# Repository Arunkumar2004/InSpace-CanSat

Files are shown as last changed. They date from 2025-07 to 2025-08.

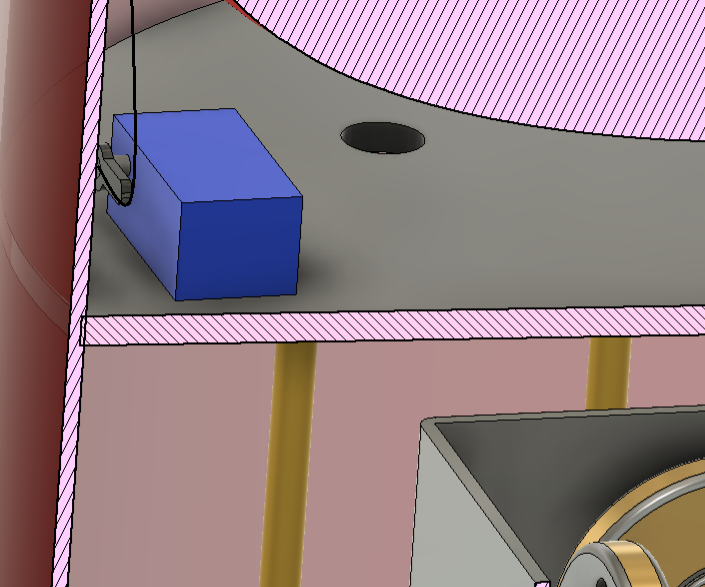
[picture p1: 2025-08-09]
IMAGE/General/para locked 1.png

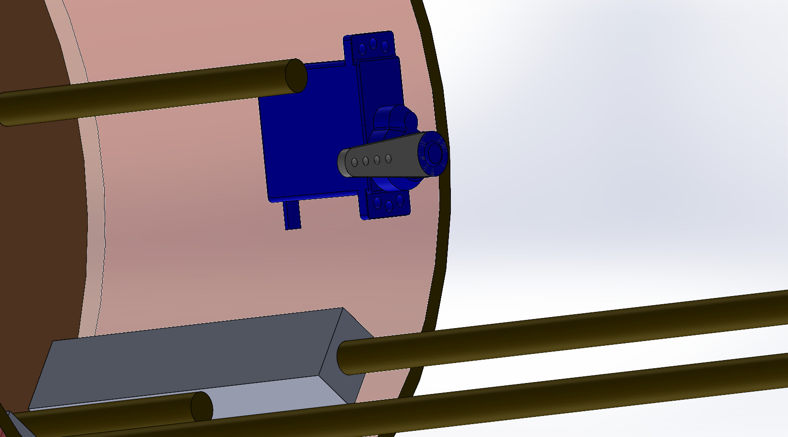
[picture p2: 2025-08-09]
IMAGE/General/Assem3.JPG

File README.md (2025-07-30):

# 🚀 INSPACE CanSat 2024-2025 – Final Stage Project

This repository contains all the work for our **CanSat project** developed for the **INSPACE CanSat Competition 2024-2025**.  
We are proud to announce that our team has been **selected for the Final Stage (Live Testing)**.

## 📌 Project Overview
Our CanSat is designed to perform a complete mission profile including:
- ✅ **CAD Design** – Full 3D modeling and structural analysis.
- ✅ **Avionics** – Flight computer, sensors, telemetry & power systems.
- ✅ **Payload** – Custom-designed scientific payload for data collection.
- ✅ **Deployment** – Safe separation and descent system.
- ✅ **Landing System** – Controlled recovery with parachute & stability testing.

## 📂 Repository Structure

## 🛰️ Technologies & Tools
- **Programming:** Python, Arduino (C/C++)
- **CAD & Simulation:** Fusion 360, SolidWorks
- **Electronics:** Teensy, Arduino Nano, Sensors (BMP, GPS, IMU)
- **Communication:** XBee Telemetry, Custom GCS Software

## 📡 Mission Objective
The goal of this CanSat is to:
- Capture real-time telemetry during flight.
- Deploy a payload safely using a controlled descent system.
- Record environmental data including temperature, pressure, and GPS coordinates.
- Successfully demonstrate deployment & landing during **INSPACE CanSat Live Testing**.

## 👨‍🚀 Team
- **Team Name:** PHOENIX
- **Members:** ARUNKUMAR D

## 🏆 Competition Status
✅ **Selected for Final Stage – Live Testing (2024-2025)**

## 📜 License
This project is licensed under the MIT License – see the [LICENSE](LICENSE) file for details.

---

### 🔗 Useful Links
- [INSPACE CanSat Competition Website](#)
- [Project Presentation](#)
- [Flight Test Videos](#)

---

⭐ **If you like this project, give it a star and follow our journey!**

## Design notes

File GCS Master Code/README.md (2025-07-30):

# CanSat GCS

Ground Control Station for Team Phoenix CanSat 2024.

## Structure
- `main.py`: Entry point
- `config/settings.py`: Serial config, team name, constants
- `serial_comm/`: Serial communication handling
- `gui/`: PyQt GUI components
- `data/`: Data logging and dummy data
- `assets/`: Images and static assets

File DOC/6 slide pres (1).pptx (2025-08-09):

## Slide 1

CanSat 2024
Preliminary Design Review (PDR)

TEAM PHOENIX

2024-ASI-CANSAT-012

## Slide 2

CANSAT configuration

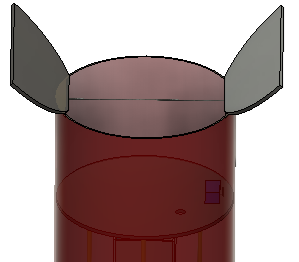
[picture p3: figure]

2nd Parachute deployed

Top Lib Opened

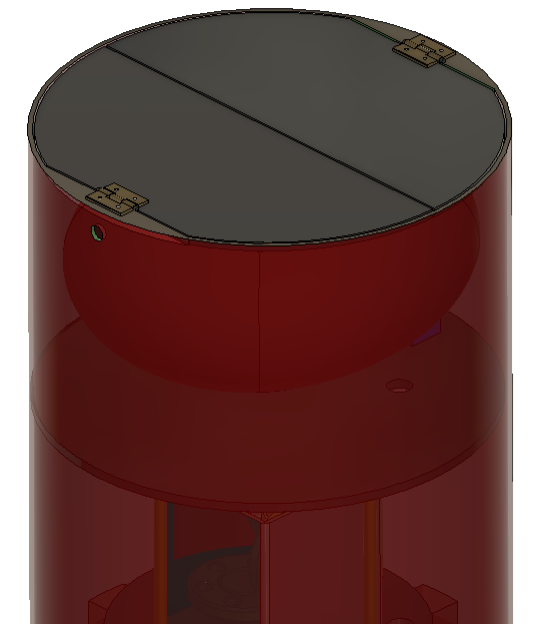
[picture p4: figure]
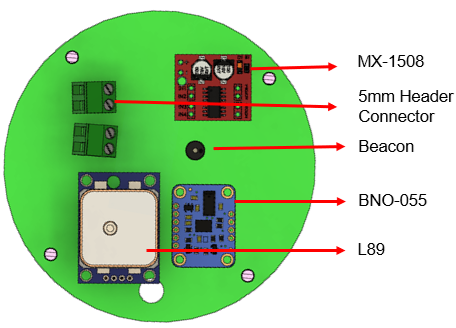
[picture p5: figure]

1st Circular PCB

Parachute Section

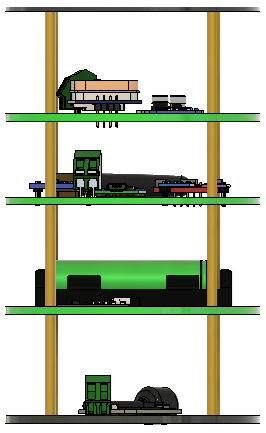
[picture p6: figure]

Payload

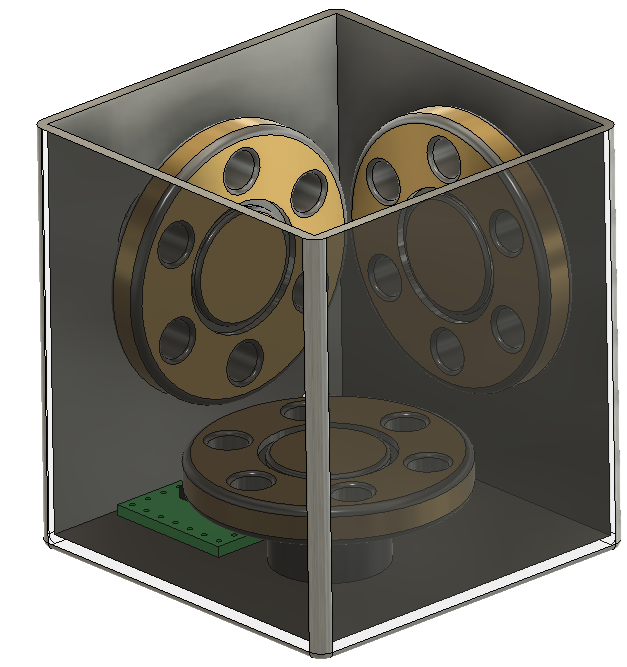
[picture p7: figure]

Gyro

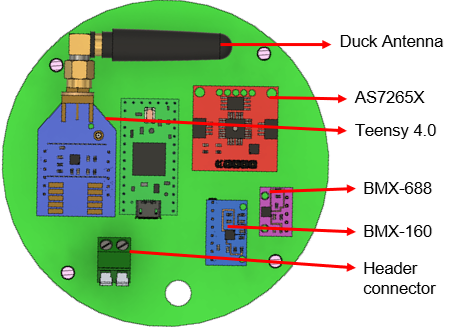
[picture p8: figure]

392MM

(Or)

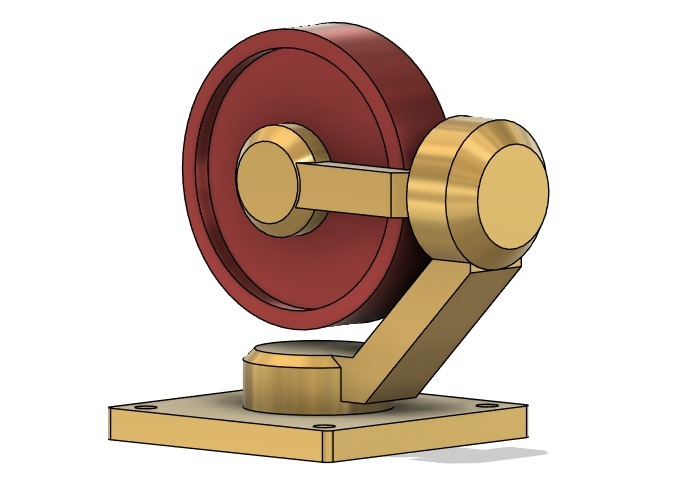
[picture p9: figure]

2nd circular PCB

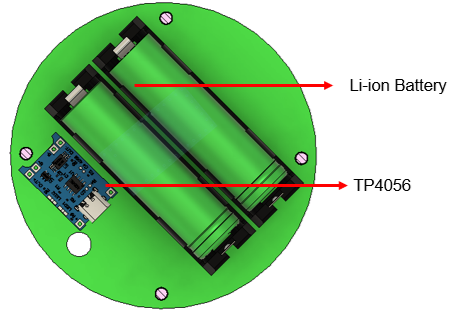
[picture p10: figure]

3rd Circular PCB

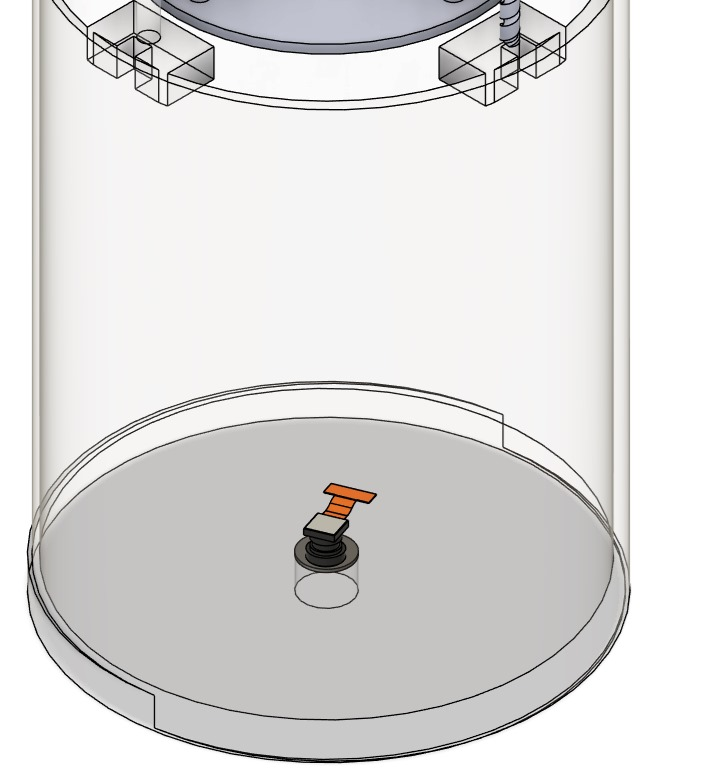
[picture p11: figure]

Camera

147 MM

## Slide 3

INNOVATION

- Automatic Expansion: CanSat expands at a specific altitude (475m).
- Direct Atmosphere Exposure: Sensors exposed immediately for accurate readings.
- Teensy Control: Teensy processor automates servo and lock mechanisms.
- Compact Design: Expands only when needed, saving space.
- Efficient Data Collection: Real-time atmospheric data at a critical altitude.

Innovation adopted by your team

locked position

- The CanSat still in contracted state from 1000 m to 475 m of altitude.

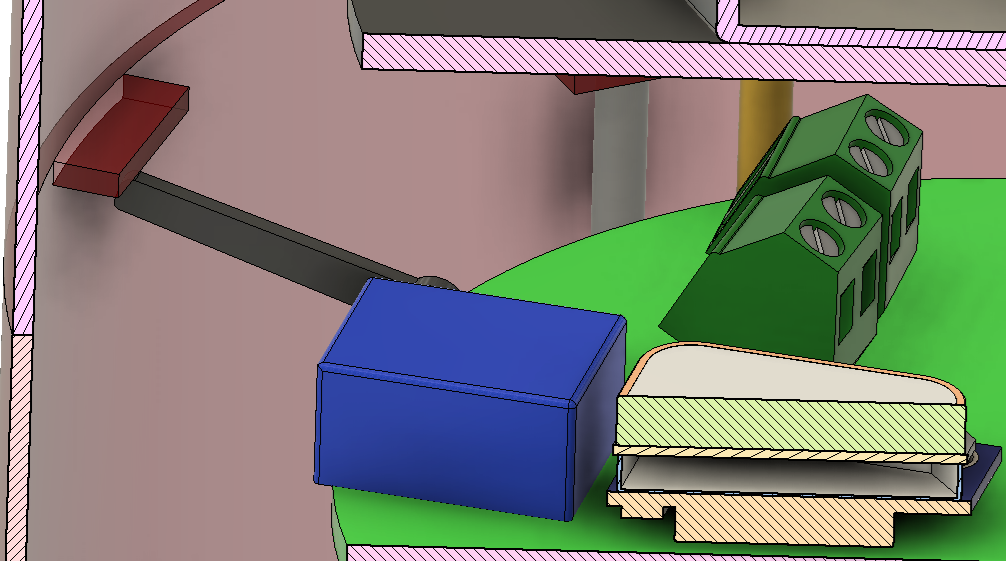
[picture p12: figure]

Unlocked position

- The CanSat in the retracted state after the altitude of 475 m.

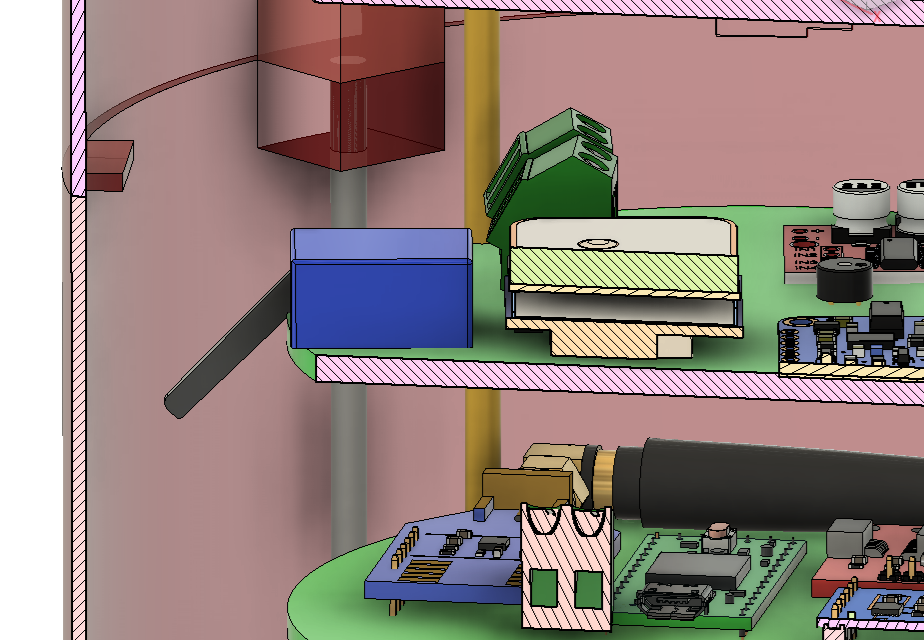
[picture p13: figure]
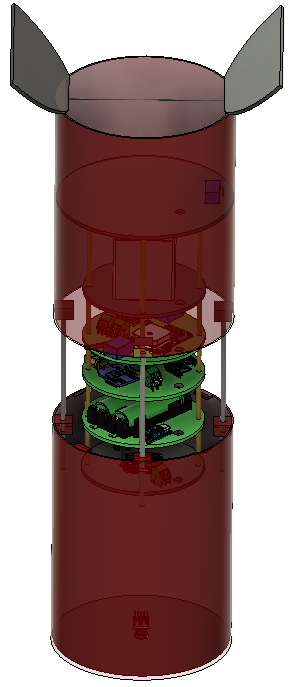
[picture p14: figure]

Launch

Altitude Check

Servo Trigger

475m Detected

Expansion

Data Collection

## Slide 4

At 475m altitude, the servo releases the lock, allowing the outer shell to retract downward.

CANSAT descent control mechanism

The first parachute deploys when the Cant is released from the rocket

- The parachute reduces the descent rate to 2 m/s.

2nd parachute deployment Mechanism

The first parachute deploys when the CanSat is released from the rocket

- The first parachute deploys when the CanSat is released from the rocket

- The first parachute is folded on the CanSat's top lid and unfolds due to air resistance, reducing the descent velocity to 15 m/s

1st parachute deployment Mechanism

locked position

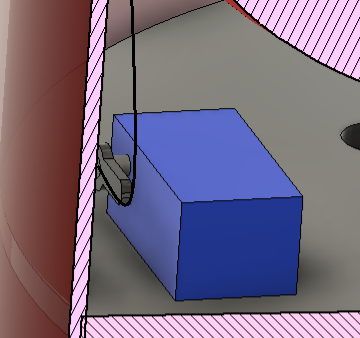
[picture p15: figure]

The first parachute deploys when the sed from the rocket

Expansion Mechanism

- At 500m altitude, the second parachute deploys using a servo lock mechanism.

Unlocked position

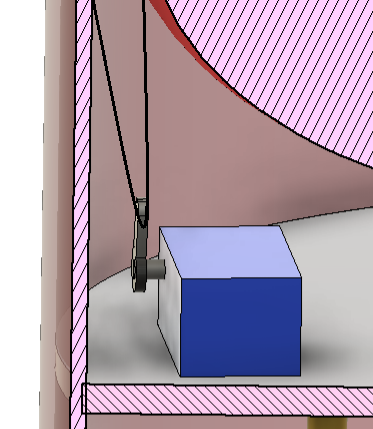
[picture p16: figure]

Deployed from Rocket

1st Parachute Deploys

1000 m

2nd Parachute Released

Expansion Mechanism Triggered

500 m

475 m

CanSat Reaches Ground

0 m

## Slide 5

Parachute design and sizing

CUBE PARACHUTE

- Primary Parachute

Descent velocity = 15 m/s
Weight = 0.85 kg
Area = 13.71 cm
Material Used = Nylon
Colour = Fluorescent Orange

- Stability: Offers better stability during descent due to its box-like shape, reducing oscillations.
- Compact Design: Easy to fold and store, making it space-efficient for deployment.

- Improved Stability: The spill hole design reduces instability and oscillations, allowing for a more controlled and stable descent.
- Improved Control: The spill hole helps regulate descent speed and reduces jerking, offering more precise control over the landing process.

Velocity - 15m/s

13.71 cm

41.13 cm

Hemispherical with spill hole - Secondary parachute

8.8 cm

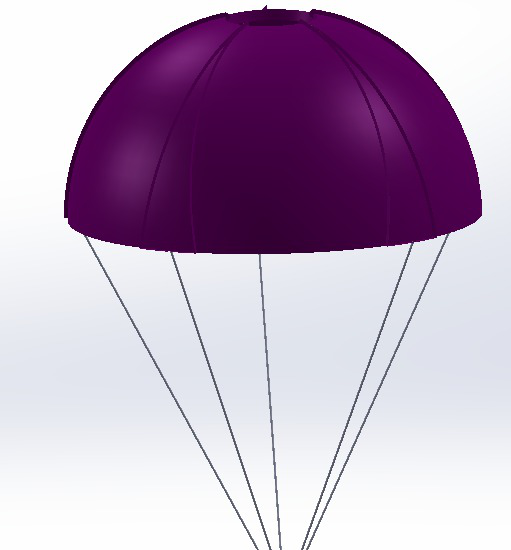
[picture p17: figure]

Velocity - 2 m/s

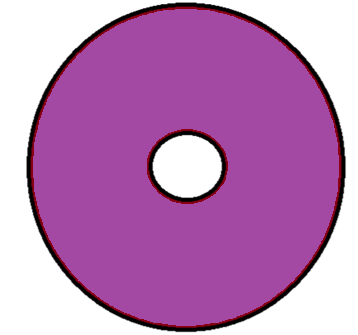
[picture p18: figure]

Descent velocity = 2 m/s
Weight = 0.85 kg
Area = 2.522 m^2
Diameter = 1.263 m
Hole = 7%
Material Used = Nylon
Colour = Voilet

126.8 cm

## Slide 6

CANSAT avionics systems

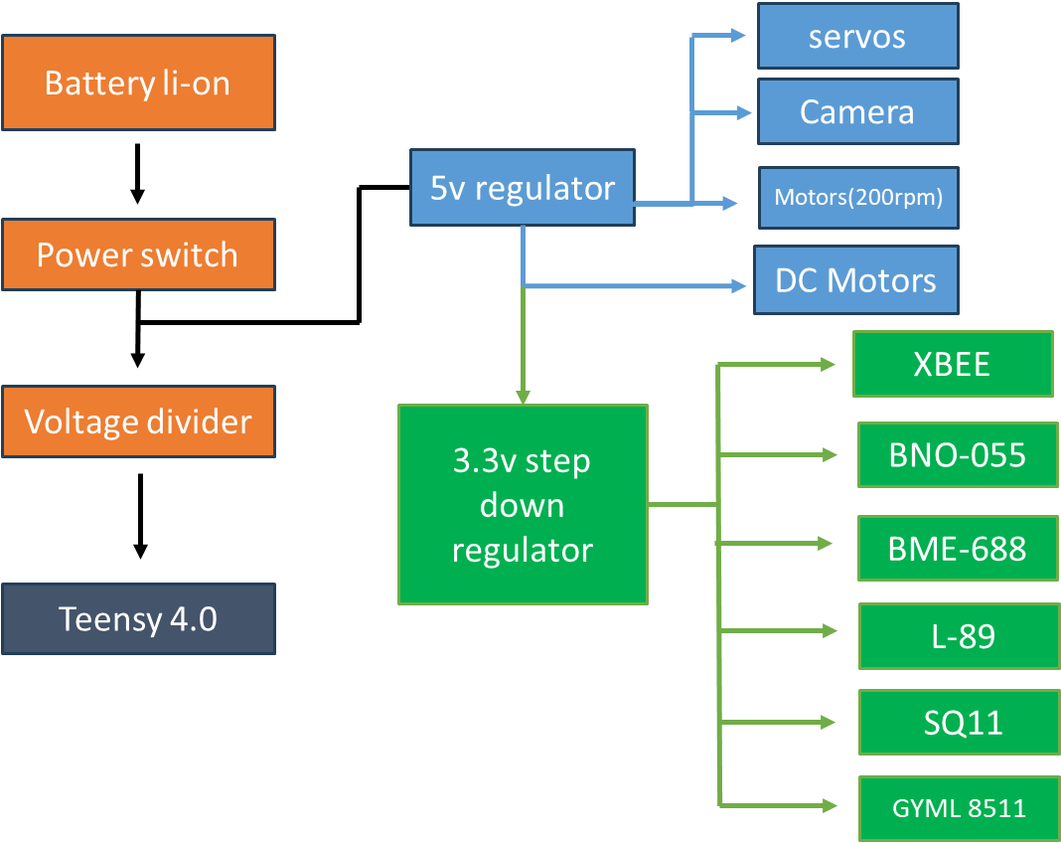
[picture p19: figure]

Power subsystem block diagram

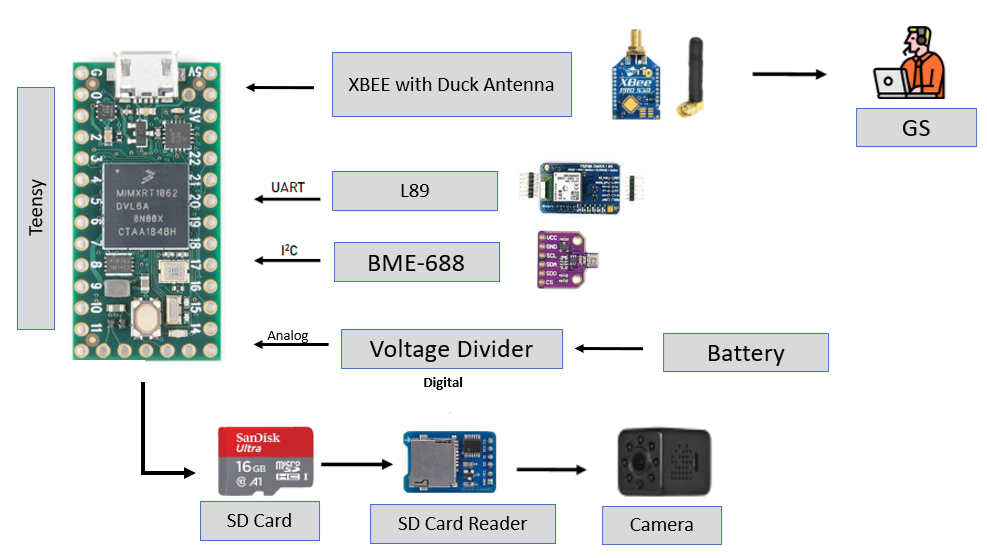
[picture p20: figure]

Communication subsystem block diagram

DC Motor

AS7265x

BMX160

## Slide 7

CANSAT mission control software and ground systems.

Overview of Mission Control Software

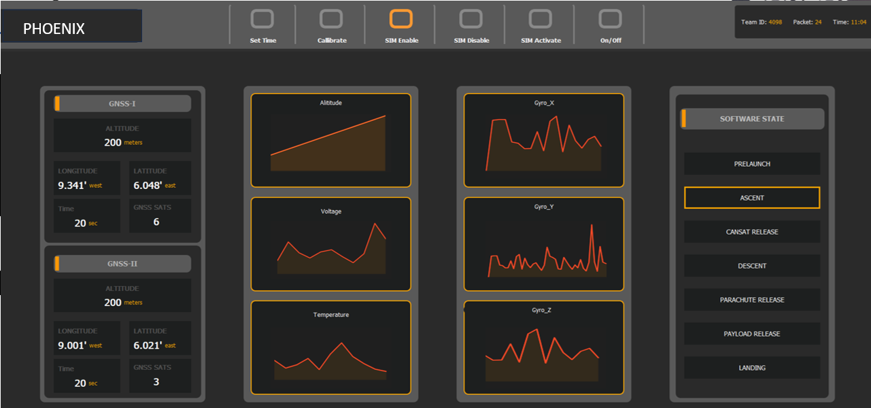
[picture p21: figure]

Ground Systems

Yagi antenna 900MHz (receiver)

Programming Language:
- C/C++ for payload hardware
- Python for ground station
Development Environment:
- Visual Studio Code

Digi XBEE pro - 900 MHz transmitter

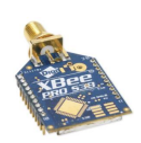
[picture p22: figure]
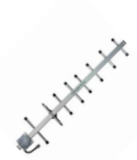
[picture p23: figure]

Digi XBEE pro - 900 MHz receiever

Mission Control Software Flow map

USB-
ADAPTOR

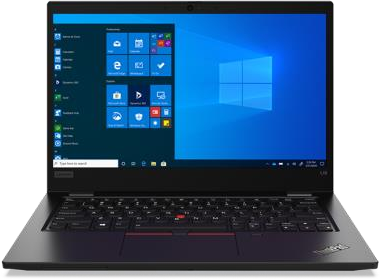
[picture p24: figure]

CanSat Data

Python Script

Data Processing

- For live video telemetry:

Telemetry Transmission

Control Logic

FPV Camera transmitter

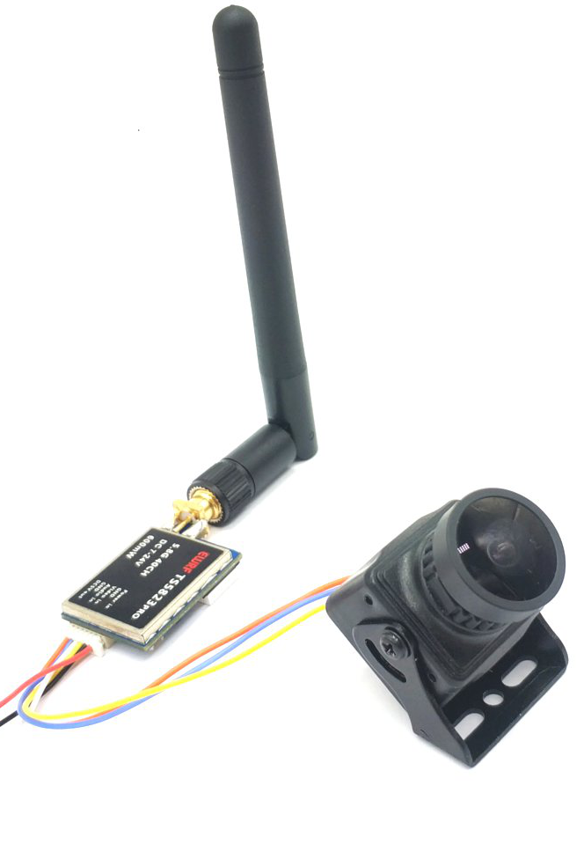
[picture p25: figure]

FPV Camera receiver

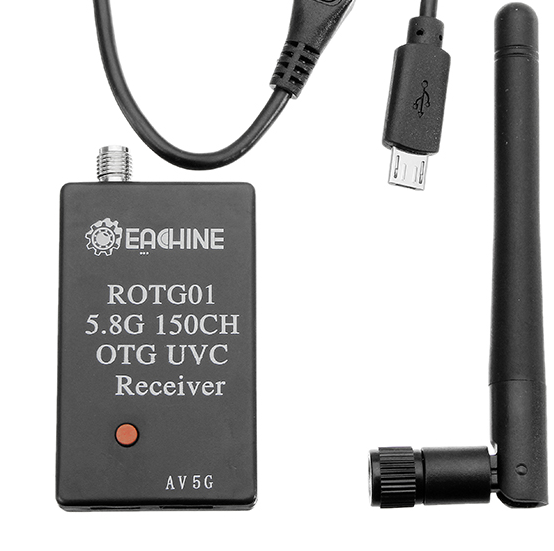
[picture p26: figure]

Ground Station Dashboard

User Action (if needed)

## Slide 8

CANSAT Mass, Cost, Power Budget and Descent Time

Total mass of electrical subsystem (g) | 240.8 g
Total mass of mechanical subsystem(g) | 610 g
Total Mass | 850.8 g

Phase | Height | Descent Rate | Descent Time
1st Parachute released | 1000m - 500m | 15 m/s | 33.7 s
2nd Parachute released | 500m - 0m | 2 m/s | 250
| Total Descent time | | 283.7 seconds

Total cost of electrical subsystem | 28217
Total cost of mechanical subsystem | 7379
Total Mass | 35595

Total mAh = 1058
- It consumes 1058 mAh of power to function for 1 Hour.
- With 2800 mAh battery it can function for 2hrs 35 mins

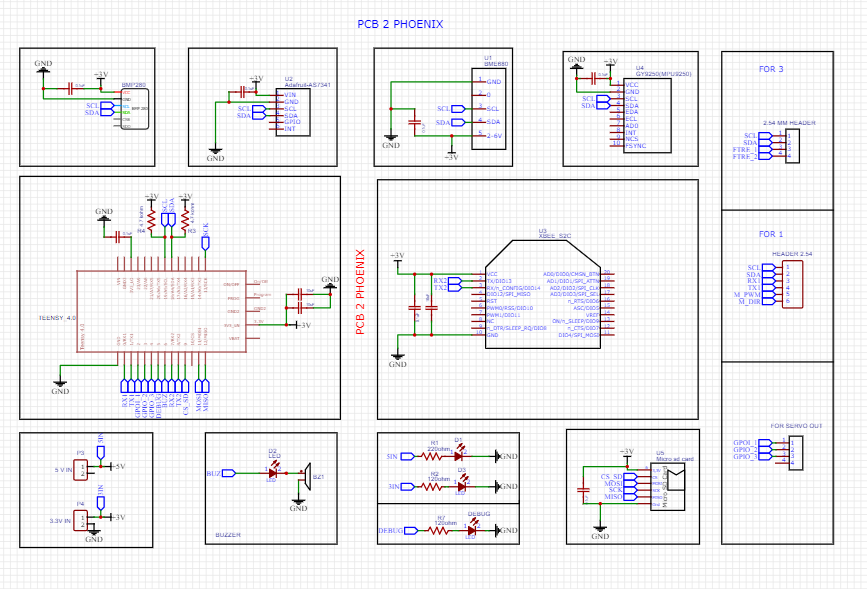
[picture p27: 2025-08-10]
PCB DESIGN/SCH IMAGE/PCB2/PCB 2 PHOENIX .png

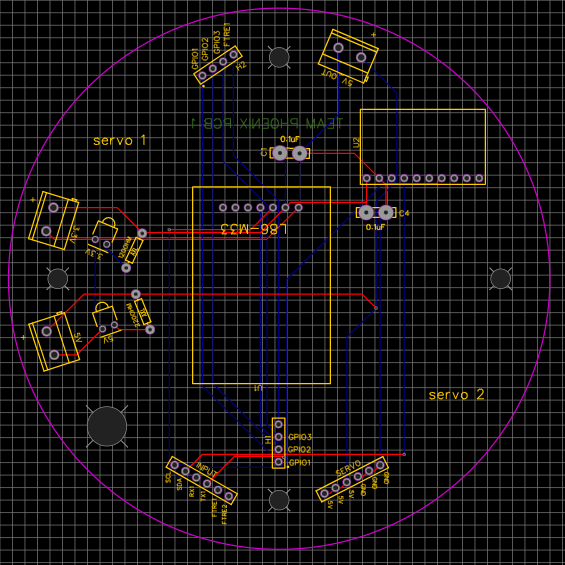
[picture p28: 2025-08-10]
PCB DESIGN/SCH IMAGE/PCB1/PCB1 SCH ROUTE.png

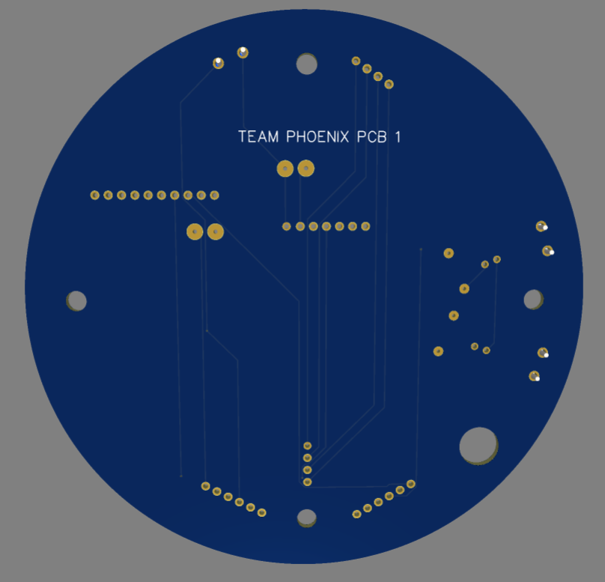
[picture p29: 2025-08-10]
PCB DESIGN/SCH IMAGE/PCB1/PCB1 BACK 3D.png

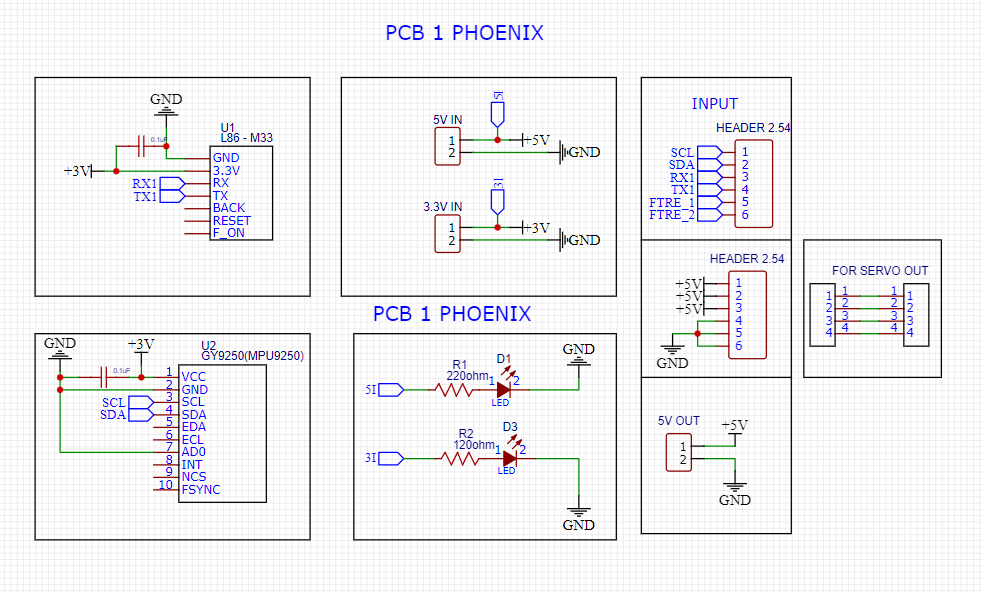
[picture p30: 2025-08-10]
PCB DESIGN/SCH IMAGE/PCB1/PCB 1 PHOENIX .png

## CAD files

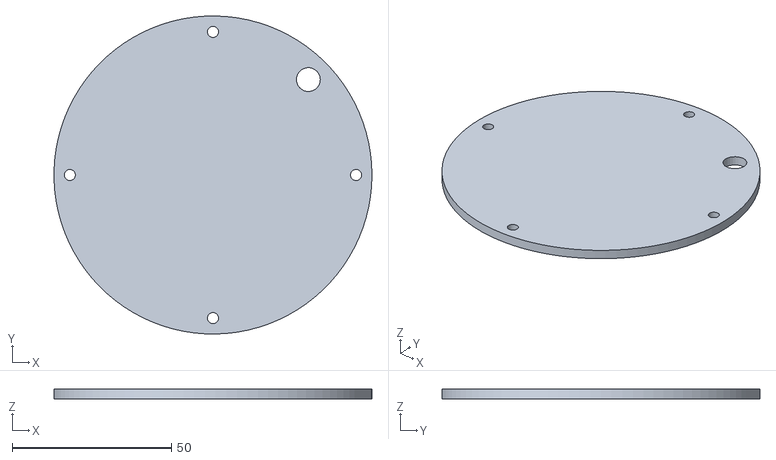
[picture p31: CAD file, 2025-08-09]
3D PRINTING/pay load plate 2 plates.stl
100.0 x 100.0 x 3.00

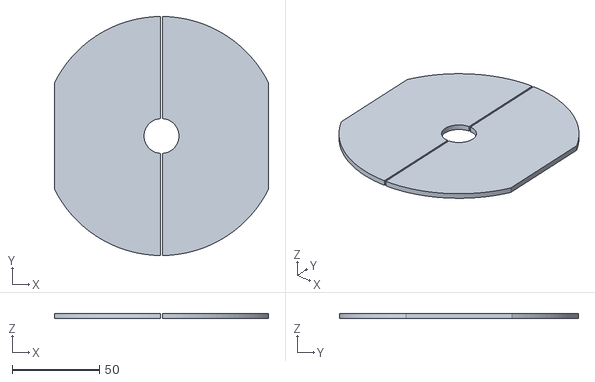
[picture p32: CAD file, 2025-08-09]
3D PRINTING/Top lib 3d print v1.stl
122.7 x 137.0 x 3.00

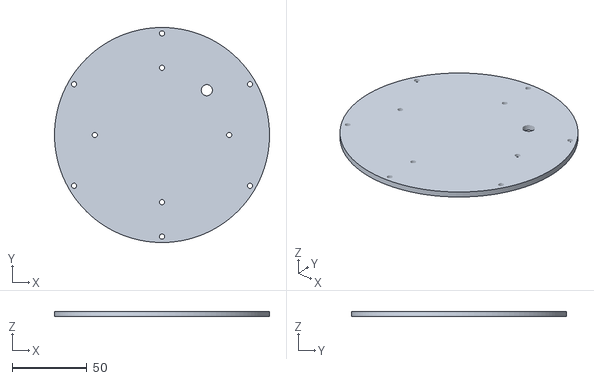
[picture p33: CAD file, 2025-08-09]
3D PRINTING/mid plate_.stl
144.0 x 144.0 x 3.50

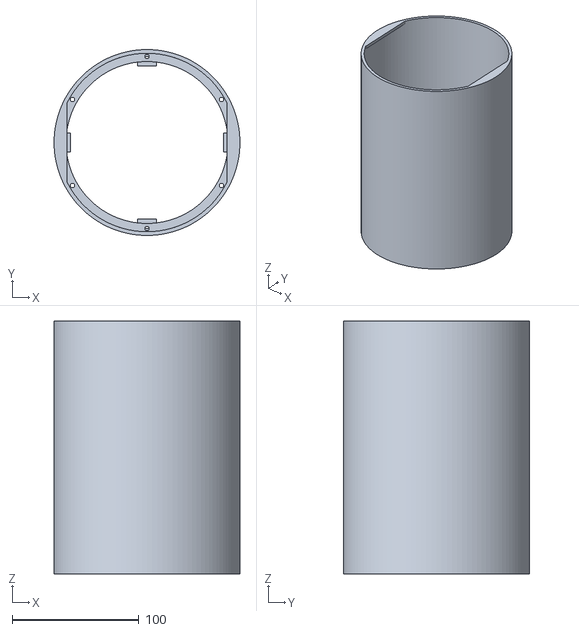
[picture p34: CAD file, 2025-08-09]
3D PRINTING/Top shell 3d print v1.stl
147.0 x 147.0 x 200.0

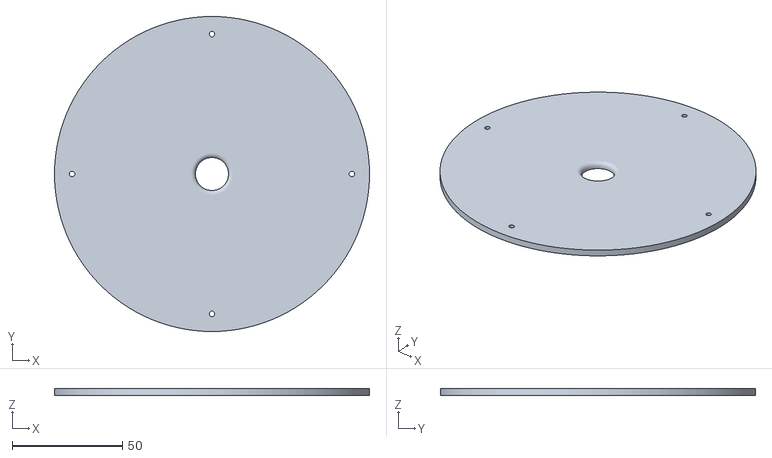
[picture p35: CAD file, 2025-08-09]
3D PRINTING/3d print down DOOR v1.stl
143.0 x 143.0 x 3.00

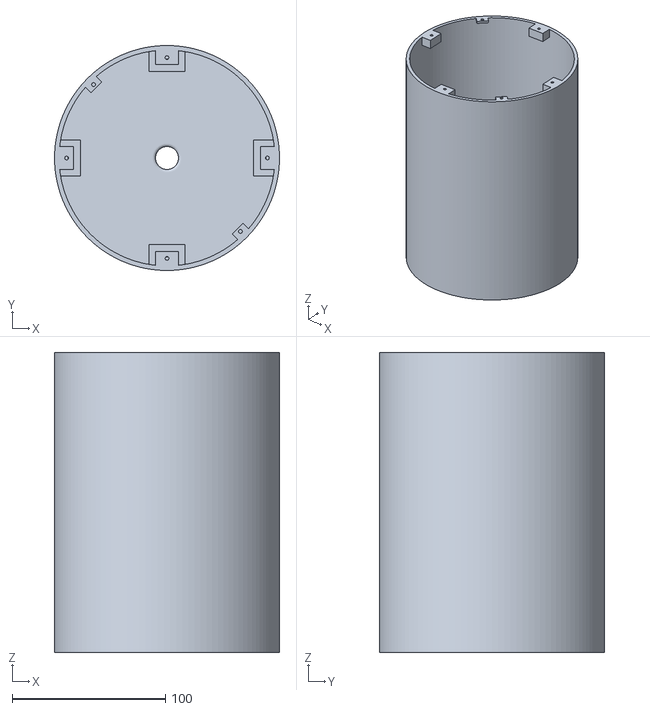
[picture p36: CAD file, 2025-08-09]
3D PRINTING/3d print down shell v3 3mm.stl
147.0 x 146.9 x 196.0

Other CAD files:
CAD MODEL/Components/Teensy_4.0_Assembly v0.step
CAD MODEL/Components/Antenna v.step
CAD MODEL/Components/Antenna v0.step
CAD MODEL/Components/Xbee my v0.step

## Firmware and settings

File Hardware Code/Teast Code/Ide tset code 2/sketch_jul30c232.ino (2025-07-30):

#include <Wire.h>
#include <Adafruit_Sensor.h>
#include <Adafruit_ADXL345_U.h>

// ADXL345 object
Adafruit_ADXL345_Unified accel = Adafruit_ADXL345_Unified();

// HW-036 sensor pin
const int sensorPin = 2;
int sensorValue = 0;

void setup() {
  Serial.begin(9600);
  pinMode(sensorPin, INPUT);
  Serial.println("HW-036 + ADXL345 Sensor Test");

  // Initialize ADXL345
  if (!accel.begin()) {
    Serial.println("Could not find ADXL345 sensor!");
    while (1);  // Halt here
  }
  accel.setRange(ADXL345_RANGE_16_G);
  Serial.println("ADXL345 initialized!");
  delay(1000);
}

void loop() {
  // Read HW-036 digital sensor
  sensorValue = digitalRead(sensorPin);

  // Read accelerometer data
  sensors_event_t event;
  accel.getEvent(&event);

  // Print all data in CSV: HW036,AccelX,AccelY,AccelZ
  Serial.print(sensorValue);
  Serial.print(",");
  Serial.print(event.acceleration.x);
  Serial.print(",");
  Serial.print(event.acceleration.y);
  Serial.print(",");
  Serial.println(event.acceleration.z);

  delay(500);
}

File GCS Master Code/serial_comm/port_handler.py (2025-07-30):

# serial_comm/port_handler.py
print("[DEBUG] Loaded serial_comm/port_handler.py")
__all__ = ["SerialHandler"]

import serial
import serial.tools.list_ports
import threading
import queue
import time
import json
from config import settings
import random

class SerialHandler:
    def __init__(self):
        self.serial_port = None
        self.running = False
        self.thread = None
        self.data_queue = queue.Queue()
        self._dummy_battery = 100.0  # For slow, monotonic battery decrease

    def list_available_ports(self):
        """Lists all available COM ports"""
        ports = serial.tools.list_ports.comports()
        return [port.device for port in ports]

    def connect(self, port=settings.SERIAL_PORT, baud=settings.BAUD_RATE):
        """Attempts to connect to the given port"""
        try:
            self.serial_port = serial.Serial(port, baudrate=baud, timeout=1)
            self.running = True
            self.thread = threading.Thread(target=self.read_serial_data, daemon=True)
            self.thread.start()
            print(f"[✓] Connected to {port} at {baud} baud.")
            return True
        except serial.SerialException as e:
            print(f"[X] Serial connection failed: {e}")
            return False

    def disconnect(self):
        """Gracefully disconnect from serial port"""
        self.running = False
        if self.serial_port and self.serial_port.is_open:
            self.serial_port.close()
            print("[!] Serial port closed.")

    def read_serial_data(self):
        """Reads incoming serial data"""
        while self.running:
            try:
                if settings.USE_DUMMY_DATA:
                    time.sleep(1)
                    dummy_data = self.generate_dummy_packet()
                    self.data_queue.put(dummy_data)
                elif self.serial_port and self.serial_port.in_waiting:
                    line = self.serial_port.readline().decode('utf-8').strip()
                    # Try JSON first
                    try:
                        data = json.loads(line)
                        self.data_queue.put(data)
                    except json.JSONDecodeError:
                        # If not JSON, try as CSV (handled in get_data)
                        if line:
                            self.data_queue.put(line)
            except Exception as e:
                print(f"[!] Serial Read Error: {e}")

    def get_data(self):
        line = None
        if not self.data_queue.empty():
            line = self.data_queue.get()
        if not line:
            return None

        # If the data is already a dict (from dummy or JSON), return as is
        if isinstance(line, dict):
            return line

        # If it's a CSV string, parse into a dict
        try:
            vals = str(line).strip().split(',')
            # Arduino output: voltage,gps_lat,gps_lon,altitude,temperature,pressure,vertical_speed,current,gyro_x,gyro_y,gyro_z,battery,time
            return {
                "voltage": float(vals[0]),
                "gps": {"lat": float(vals[1]), "lon": float(vals[2])},
                "altitude": float(vals[3]),
                "temperature": float(vals[4]),
                "pressure": float(vals[5]),
                "vertical_speed": float(vals[6]),
                "current": float(vals[7]),
                "gyro": {"x": float(vals[8]), "y": float(vals[9]), "z": float(vals[10])},
                "battery": float(vals[11]),
                "time": vals[12]
            }
        except Exception as e:
            print("Parse error:", e, "Raw:", line)
            return None
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

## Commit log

2025-07-30 The first gui & hardware data uploaded
    [recording_20250730_065432.csv]
2025-08-09 PCB was uploaded
2025-08-09 3d print, cad , doc, image Uploaded
    [3d print down DOOR v1.stl, 3d print down shell v3 3mm.stl, Antenna v.step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]
2025-08-10 All image added for all pcb, and all pcb file updated
